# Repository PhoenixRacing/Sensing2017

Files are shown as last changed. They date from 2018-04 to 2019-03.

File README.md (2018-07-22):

# Olin College of Engineering Baja Electrical Subteam Repository

## Backbox

Contains the back-end files (.ino) for the various Arduinos responsible for communication and various tasks relating to reading in sensor data and passing it to the dashboard and SD card.

## Dashboard

Contains the files (.ino) necessary for communicating between the dashboard Arduino and the backbox, as well as for displaying information to the driver as well as logging the information the SD card.

## Dependencies

Contains the libraries necessary to making the code compile on the Arduinos.

## Examples

Contains example code for the various components of the electrical subsystem (refer to system architecture diagram); utilize this for reference for skeleton code.

## LogFiles

Contains (or will contain) the log files saved on the SD card from the car. Will either be in .csv or.xlsx format.

## Outdated Code

Contains archival code from past years that has been ommitted for various reasons (didn't work, redone, unnecessary).

## i2cSlaveTest

Will be absorbed underneath Examples directory eventually. Contains example code for a test for communication between two Arduinos over i2c.

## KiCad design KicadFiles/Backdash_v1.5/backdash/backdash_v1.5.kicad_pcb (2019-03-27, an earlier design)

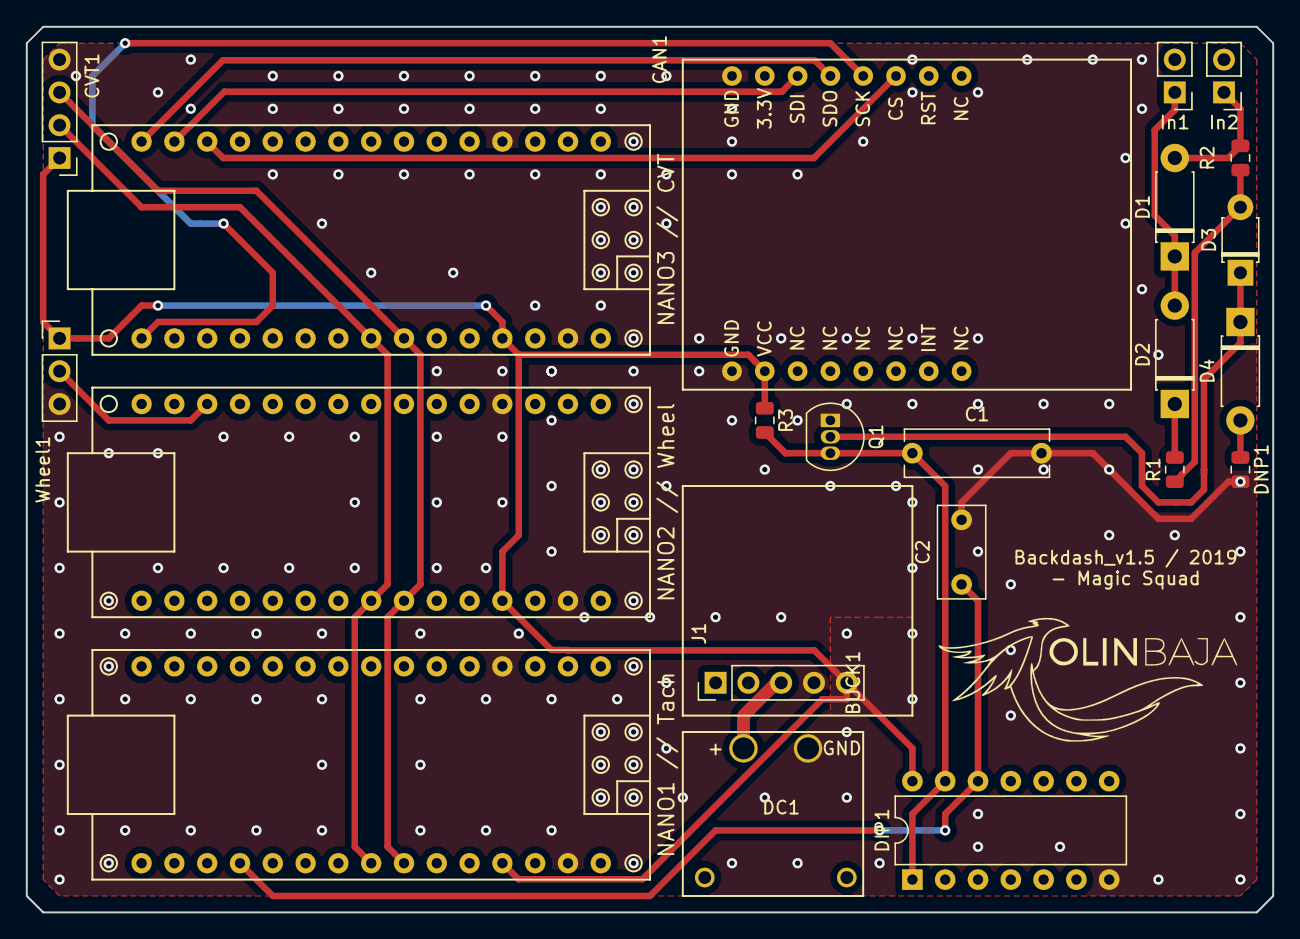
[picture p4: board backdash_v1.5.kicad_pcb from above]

Board: 2 copper layers, 96.5 x 68.6 mm, 22 parts (0 on the bottom side), 19 nets.

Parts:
BUCK1: Conn_01x05_Female; Buck_module
C1: 2200pF; C_Rect_L11.0mm_W3.5mm_P10.00mm_MKT
C2: 39nF; C_Rect_L7.0mm_W3.5mm_P5.00mm
CAN1: Conn_01x16_Female; CAN_Module
CVT1: Conn_01x04_Female; PinHeader_1x04_P2.54mm_Vertical
D1, D2: 1N4007; D_DO-41_SOD81_P7.62mm_Horizontal
D3: 1N4148; D_T-1_P5.08mm_Horizontal
D4: 1N4738; D_DO-41_SOD81_P7.62mm_Horizontal
DC1: Conn_01x04_Female; DC_Connector
DIP1: SN74HC14N; DIP-14_W7.62mm
DNP1: DNP; R_0805_2012Metric
In1: Vin +; PinHeader_1x02_P2.54mm_Vertical
In2: Vin-; PinHeader_1x02_P2.54mm_Vertical
NANO1 // Tach, NANO2 // Wheel, NANO3 // CVT: Conn_01x30_Female; arduino_nano
Q1: 2N3904; TO-92_Inline
R1, R2: 10k; R_0805_2012Metric
R3: 4.7k; R_0805_2012Metric
Wheel1: Conn_01x03_Female; PinHeader_1x03_P2.54mm_Vertical

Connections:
/+: BUCK1.3, DC1.2
/A0: C2.1, DIP1.12, NANO1 // Tach.19
/A4: CVT1.2, NANO1 // Tach.23, NANO2 // Wheel.23, NANO3 // CVT.23
/A5: CVT1.3, NANO1 // Tach.24, NANO2 // Wheel.24, NANO3 // CVT.24
/CS: CAN1.6, NANO3 // CVT.13
/D10: NANO2 // Wheel.13, Wheel1.2
/GND: BUCK1.4, C1.2, C2.2, CAN1.1, CAN1.16, CVT1.4, DC1.1, DIP1.7, DNP1.2, NANO1 // Tach.4, NANO1 // Tach.29, NANO2 // Wheel.4, NANO2 // Wheel.29, NANO3 // CVT.4, NANO3 // CVT.29, Q1.1, Wheel1.3
/RST: CAN1.7, NANO1 // Tach.3, NANO1 // Tach.28, NANO2 // Wheel.3, NANO2 // Wheel.28, NANO3 // CVT.3, NANO3 // CVT.28
/SCK: CAN1.5, NANO3 // CVT.16
/SDI: CAN1.3, NANO3 // CVT.14
/SDO: CAN1.4, NANO3 // CVT.15
/VCC: BUCK1.5, CAN1.15, CVT1.1, DIP1.14, NANO1 // Tach.27, NANO2 // Wheel.27, NANO3 // CVT.27, R3.1, Wheel1.1
unnamed: C1.1, DIP1.1, DIP1.13, Q1.3, R3.2
unnamed: D1.1, D2.2, In1.1
unnamed: D1.2, In2.1, R2.1
unnamed: D2.1, R1.2
unnamed: D3.1, D4.1, Q1.2
unnamed: D3.2, R1.1, R2.2
unnamed: D4.2, DNP1.1

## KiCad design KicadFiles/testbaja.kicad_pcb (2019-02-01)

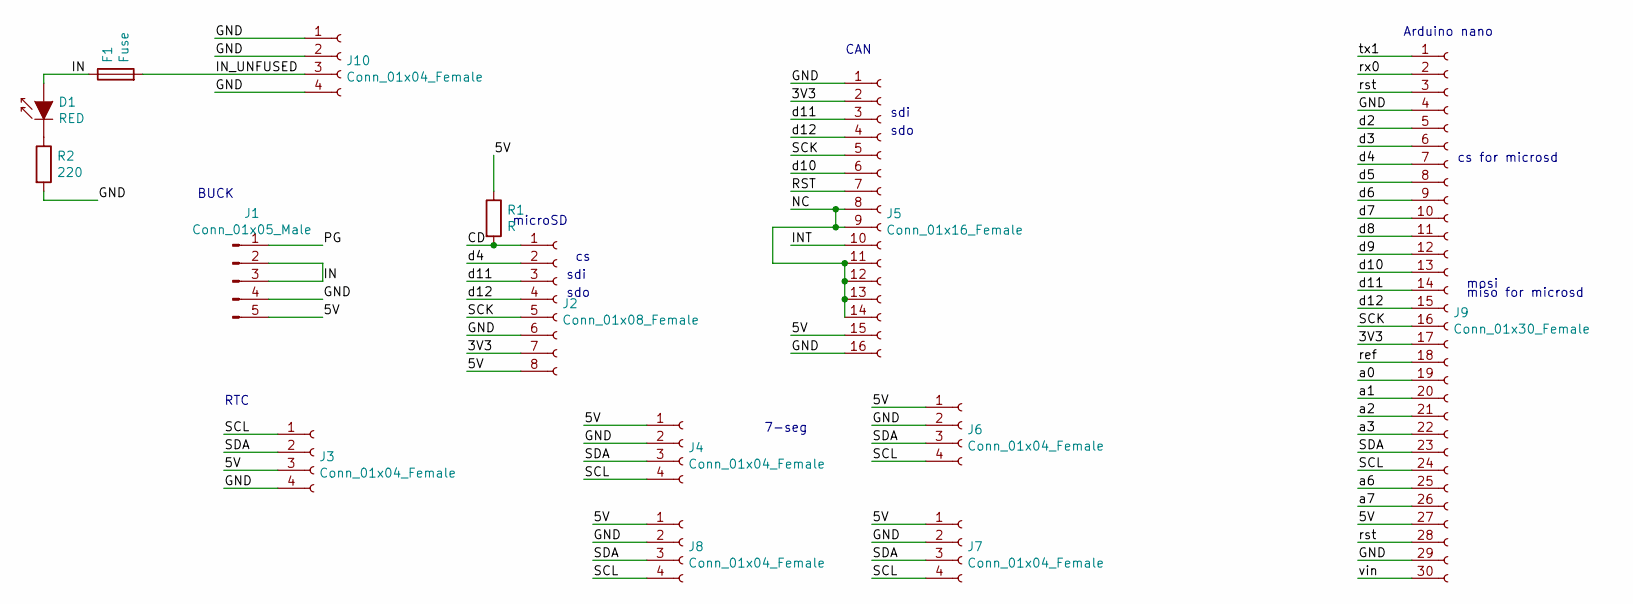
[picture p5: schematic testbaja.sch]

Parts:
D1: RED; LED_D5.0mm_FlatTop
F1: Fuse; Fuse_0ZCFSeries
J1: Conn_01x05_Male; Buck_module
J2: Conn_01x08_Female; microSD_module
J3: Conn_01x04_Female; RealTimeClock
J4, J6, J7, J8: Conn_01x04_Female; 7_segment_display
J5: Conn_01x16_Female; CAN_Module
J9: Conn_01x30_Female; arduino_nano
J10: Conn_01x04_Female; DC_Connector
R1: R; R_1206_3216Metric_Pad1.42x1.75mm_HandSolder
R2: 220; R_0805_2012Metric

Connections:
/3V3: J2.7, J5.2, J9.17
/5V: J1.5, J2.8, J3.3, J4.1, J5.15, J6.1, J7.1, J8.1, J9.27, R1.1
/CD: J2.1, R1.2
/GND: J1.4, J2.6, J3.4, J4.2, J5.1, J5.16, J6.2, J7.2, J8.2, J9.4, J9.29, J10.1, J10.2, J10.4, R2.2
/IN: D1.2 (A), F1.1, J1.2, J1.3
/INT: J5.10
/IN_UNFUSED: F1.2, J10.3
/NC: J5.8, J5.9, J5.11, J5.12, J5.13, J5.14
/PG: J1.1
/RST: J5.7
/SCK: J2.5, J5.5, J9.16
/SCL: J3.1, J4.4, J6.4, J7.4, J8.4, J9.24
/SDA: J3.2, J4.3, J6.3, J7.3, J8.3, J9.23
/a0: J9.19
/a1: J9.20
/a2: J9.21
/a3: J9.22
/a6: J9.25
/a7: J9.26
/d2: J9.5
/d3: J9.6
/d4: J2.2, J9.7
/d5: J9.8
/d6: J9.9
/d7: J9.10
/d8: J9.11
/d9: J9.12
/d10: J5.6, J9.13
/d11: J2.3, J5.3, J9.14
/d12: J2.4, J5.4, J9.15
/ref: J9.18
/rst: J9.3, J9.28
/rx0: J9.2
/tx1: J9.1
/vin: J9.30
unnamed: D1.1 (K), R2.1

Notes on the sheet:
microSD
BUCK
RTC
7-seg
CAN
Arduino nano
cs for microsd
miso for microsd
mosi
sdi
sdo

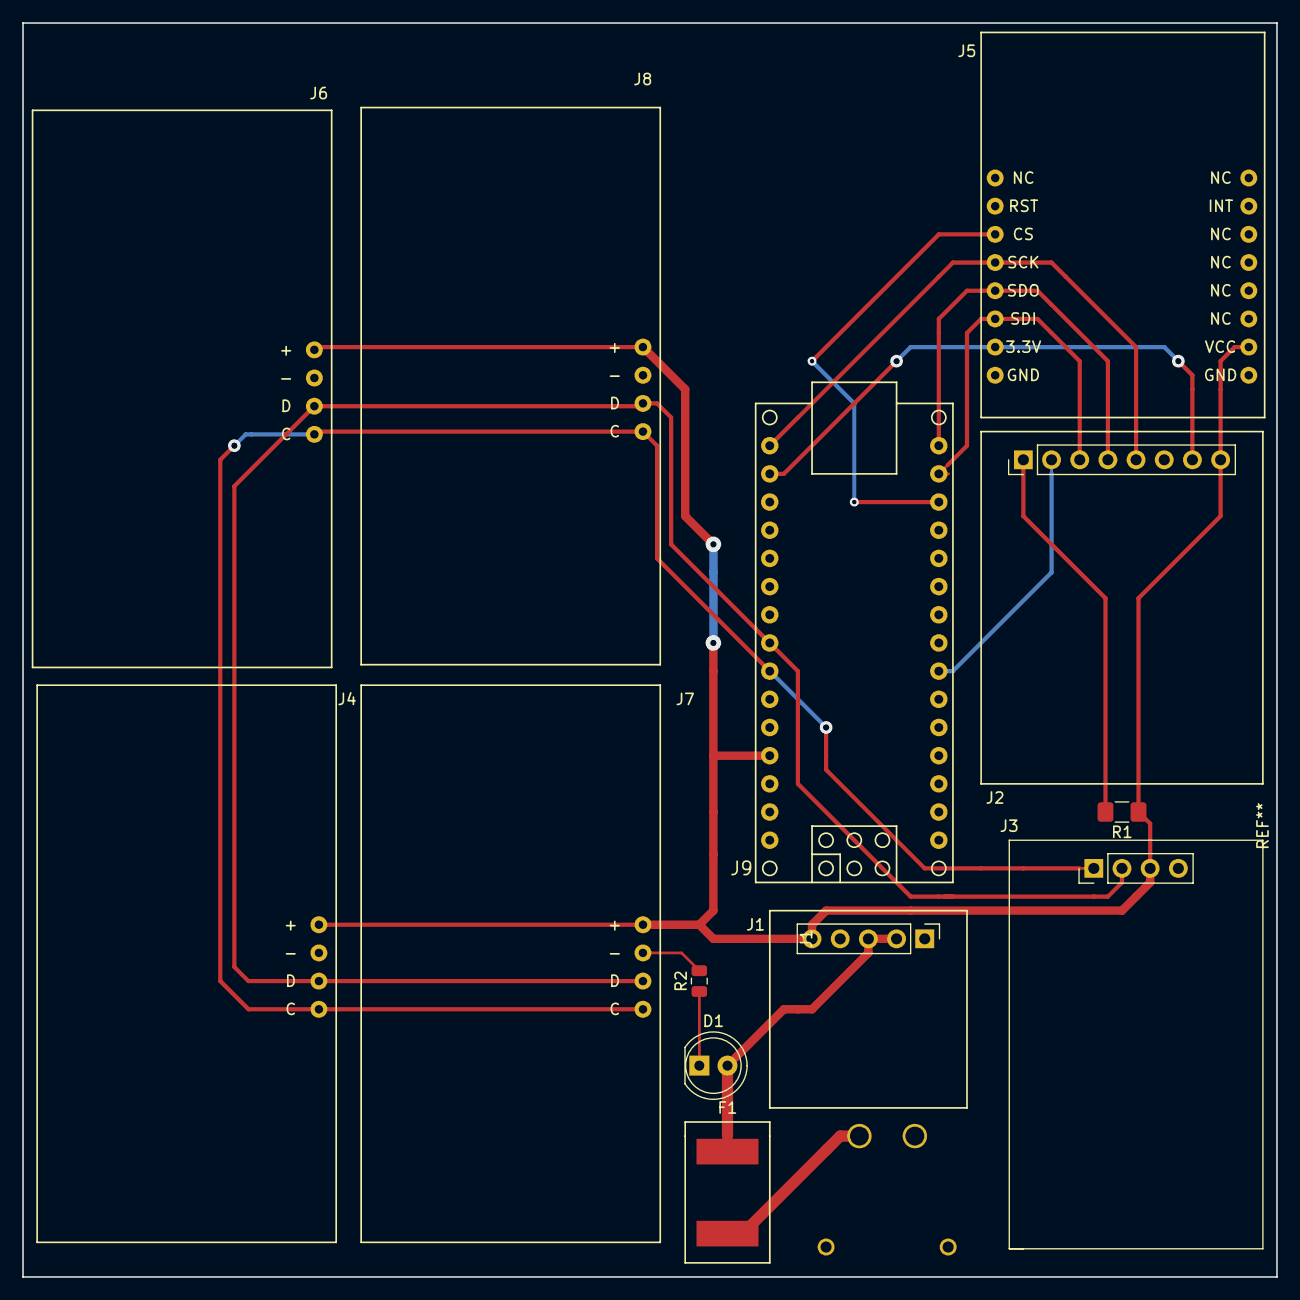
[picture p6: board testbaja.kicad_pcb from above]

Board: 2 copper layers, 113.0 x 113.0 mm, 14 parts (1 on the bottom side), 16 nets.

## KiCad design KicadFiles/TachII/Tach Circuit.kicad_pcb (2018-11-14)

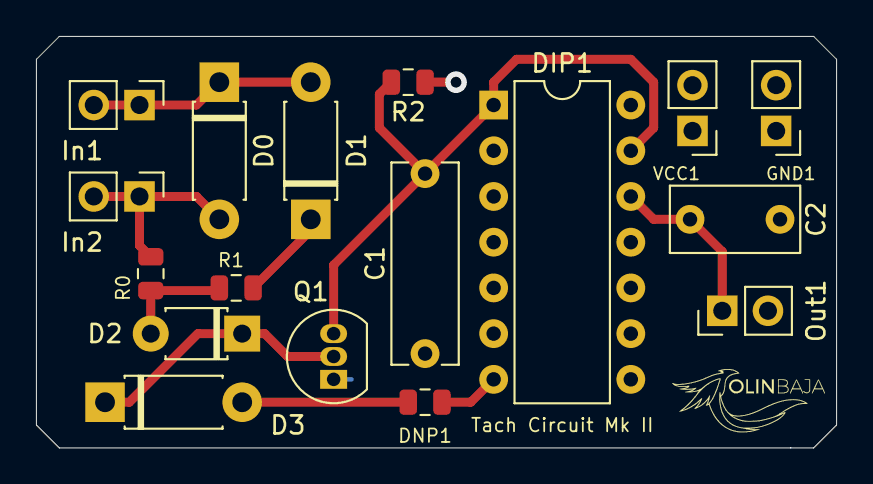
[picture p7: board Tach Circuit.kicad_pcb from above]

Board: 2 copper layers, 44.4 x 22.9 mm, 17 parts (0 on the bottom side), 10 nets.

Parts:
C1: 2200pF; C_Rect_L11.0mm_W3.5mm_P10.00mm_MKT
C2: 39nF; C_Rect_L7.0mm_W3.5mm_P5.00mm
D0, D1: 1N4007; D_DO-41_SOD81_P7.62mm_Horizontal
D2: 1N4148; D_T-1_P5.08mm_Horizontal
D3: 1N4738; D_DO-41_SOD81_P7.62mm_Horizontal
DIP1: SN74HC14N; DIP-14_W7.62mm
DNP1: DNP; R_0805_2012Metric
GND1: GND; PinHeader_1x02_P2.54mm_Vertical
In1: Vin +; PinHeader_1x02_P2.54mm_Vertical
In2: Vin-; PinHeader_1x02_P2.54mm_Vertical
Out1: Vout; PinHeader_1x02_P2.54mm_Vertical
Q1: 2N3904; TO-92_Inline
R0, R1: 10k; R_0805_2012Metric
R2: 4.7k; R_0805_2012Metric
VCC1: 5V; PinHeader_1x02_P2.54mm_Vertical

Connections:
+5V: DIP1.14, R2.1, VCC1.1
GND: C1.2, C2.2, DIP1.7, DNP1.2, GND1.1, Q1.1
unnamed: C1.1, DIP1.1, DIP1.13, Q1.3, R2.2
unnamed: C2.1, DIP1.12, Out1.1
unnamed: D0.1, D1.2, In1.1
unnamed: D0.2, In2.1, R0.1
unnamed: D1.1, R1.2
unnamed: D2.1, D3.1, Q1.2
unnamed: D2.2, R0.2, R1.1
unnamed: D3.2, DNP1.1

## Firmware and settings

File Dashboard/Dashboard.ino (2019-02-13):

/*
 *  - Check for data from CAN --> for the time being just if(True) {
 *  --> update averages --> acceptSample(&tach, analogRead(1)) (inside if statement)
 *  - write to displays
 *  - check if it's been long enough since SD write
 *  --> write to SD --> read RTC
 *  - clear averages
 *  
 *               AT REAR | AT DASH | DISPLAY
 * Wheel Speed | *100    | /100    | 0-40mph
 * Tach        | *1      | *1      | 1000-4000
 * GB Temp     | *1      | *1      | 10-120 C
 * CVT Temp    | *1      | *1      | 10-120 C
 */

//#define DEBUG

/*ERROR CODES:
E 01: RTC failed initialization
E 02: RTC time has been lost
E 03: SD failed initialization
E 04: CAN failed initialization
E 05: File creation failed
*/

#include <Wire.h>
#include <Adafruit_GFX.h>
#include "Adafruit_LEDBackpack.h"
#include "RTClib.h"
#include <SPI.h>
#include <SD.h>
#include <mcp_can.h>
/* Display segment layout:

     8
   -----
 3| 2  |7
   -----
 4| 5  |6
   -----  .1

*/

#define LETTER_O B00111111
#define LETTER_L B00111000
#define LETTER_I B00000110
#define LETTER_n B01010100
#define LETTER_b B01111100
#define LETTER_A B01110111
#define LETTER_J B00011110
#define LETTER_E B01111001
#define LETTER_r B01010000

RTC_DS3231 rtc;
File logFile;
char fileName[13];
boolean logFlag = false;


#define SPEEDO_POS 0
#define TACH_POS 1
#define CVT_POS 2
#define GEARBOX_POS 3

#define BUTTON_PIN 2 //logger button pin 2

#define REFRESH_TIME 100

#define ERROR_DISPLAY_TIME 500

//long unsigned int rxId = 0x101;
#define DATA_LEN 4
uint8_t rxBuf[DATA_LEN*sizeof(int)];         //raw data from CAN
unsigned int recentData[DATA_LEN];             //data from CAN converted back to ints
//#define CAN0_INT 2                          // Set INT to pin 2
MCP_CAN CAN0(10);                           // Set CS to pin 10


typedef struct {
  float sum;
  int count;
} average_data;

average_data tach;
average_data speedo;
average_data cvtTemp;
average_data gearBoxTemp;

void acceptSample(average_data *avg, float data) {
  avg -> sum += data;
  avg -> count++;
}

float getAverage(average_data *avg) {
    float sum = avg -> sum;
    int n = avg -> count;
    return (sum/n);
}

void resetAverage(average_data *avg) {
  avg -> sum = 0;
  avg -> count = 0;
}

Adafruit_7segment tachDisp = Adafruit_7segment();
Adafruit_7segment speedoDisp = Adafruit_7segment();
Adafruit_7segment cvtTempDisp = Adafruit_7segment();
Adafruit_7segment gearBoxTempDisp = Adafruit_7segment();

void initializeDisplays(){
  tachDisp.begin(0x73);
  speedoDisp.begin(0x70);
  cvtTempDisp.begin(0x74);
  gearBoxTempDisp.begin(0x72);
  tachDisp.setBrightness(15);
  speedoDisp.setBrightness(15);
  cvtTempDisp.setBrightness(15);
  gearBoxTempDisp.setBrightness(15);
}

void writeDisplays(){
  tachDisp.writeDisplay();
  speedoDisp.writeDisplay();
  cvtTempDisp.writeDisplay();
  gearBoxTempDisp.writeDisplay();
}

void displayStartup(){
  speedoDisp.writeDigitRaw(0,LETTER_O);
  speedoDisp.writeDigitRaw(1,LETTER_L);
  speedoDisp.writeDigitRaw(3,LETTER_I);
  speedoDisp.writeDigitRaw(4,LETTER_n);
  tachDisp.writeDigitRaw(0,LETTER_b);
  tachDisp.writeDigitRaw(1,LETTER_A);
  tachDisp.writeDigitRaw(3,LETTER_J);
  tachDisp.writeDigitRaw(4,LETTER_A);
  cvtTempDisp.println(2017);
  gearBoxTempDisp.println(2018);
  writeDisplays();
}

void displayZero(){
  tachDisp.println(0);
  speedoDisp.println(0);
  cvtTempDisp.println(0);
  gearBoxTempDisp.println(0);
  writeDisplays();
}

void displayClear(){
  tachDisp.println();
  speedoDisp.println();
  cvtTempDisp.println();
  gearBoxTempDisp.println();
  writeDisplays();
}

void displayError(int code){
  gearBoxTempDisp.writeDigitRaw(0,LETTER_E);
  gearBoxTempDisp.writeDigitRaw(1,LETTER_r);
  gearBoxTempDisp.writeDigitNum(3,int(code/10));
  gearBoxTempDisp.writeDigitNum(4,code%10);
  gearBoxTempDisp.drawColon(1);
  writeDisplays();
}

#define WRITE_INTERVAL 5000

unsigned long lastWriteTime = 0;

void writeLine(unsigned int tachData, float speedData, unsigned int cvtData, unsigned int gbData, boolean logger){
  DateTime logTime = rtc.now();
  char line[27];
  char MM[4];
  char SS[4];
  char SPED[6];
  char TACH[6];
  char CVT[5];
  char GBT[5];
  char F[3];

  if(logger) {
    F[0] = '1';
  }
  else {
    F[0] = '0';
  }
  F[1] = ',';
    
  sprintf(line,"%02d:", logTime.hour());
  sprintf(MM, "%02d:", logTime.minute());
  sprintf(SS, "%02d,", logTime.second());
  //sprintf included with arduino does not handle floats, so this:
  sprintf(SPED, "%02d.%01d,", int(speedData), (round(speedData*10)%10));
  sprintf(TACH, "%04d,", tachData);
  sprintf(CVT, "%03d,", round(cvtData));
  sprintf(GBT, "%03d,", round(gbData));

  strcat(line, MM);
  strcat(line, SS);
  strcat(line, SPED);
  strcat(line, TACH);
  strcat(line, CVT);
  strcat(line, GBT);
  strcat(line, F);

  #ifdef DEBUG
    Serial.println(line);
  #endif

  logFile = SD.open(fileName, FILE_WRITE);
  if(logFile){
    logFile.println(line);
    logFile.close();
  }
}

void setup() {
#ifdef DEBUG
  Serial.begin(9600);
  Serial.println("Starting Dash Display and Logger in Debug Mode...");
#endif

  initializeDisplays();

  Wire.begin();        // Activate I2C link

  displayStartup();
  delay(3000);
  displayZero();
  pinMode(BUTTON_PIN,INPUT_PULLUP);

  if(!rtc.begin()){
    displayError(1);
    #ifdef DEBUG
      Serial.println("RTC failed initialization");
    #endif
    delay(ERROR_DISPLAY_TIME);
  }

  if (rtc.lostPower()) {
    displayError(2);
    #ifdef DEBUG
      Serial.println("RTC time has been lost");
    #endif
    delay(ERROR_DISPLAY_TIME);
  }

  if (!SD.begin(4)){
    displayError(3);
    #ifdef DEBUG
      Serial.println("SD failed initialization");
    #endif
    delay(ERROR_DISPLAY_TIME);
  }


  // Initialize MCP2515 running at 16MHz with a baudrate of 500kb/s and the masks and filters disabled.
  if(!CAN0.begin(MCP_ANY, CAN_500KBPS, MCP_16MHZ) == CAN_OK){
    displayError(4);
    #ifdef DEBUG
      Serial.println("CAN failed initialization");
    #endif
    delay(ERROR_DISPLAY_TIME);
  }


  
  CAN0.setMode(MCP_NORMAL);                     // Set operation mode to normal so the MCP2515 sends acks to received data. //makes the Message Sent successfully on the RX side. 
  //pinMode(CAN0_INT, INPUT);                     // Configuring pin for /INT input

  DateTime now = rtc.now();
  char MO[3];
  char DD[3];
  char HH[3];
  char MI[3];
  sprintf(MO, "%02d", now.month());
  sprintf(DD, "%02d", now.day());
  sprintf(HH, "%02d", now.hour());
  sprintf(MI, "%02d", now.minute());
  strcat(fileName, MO);
  strcat(fileName, DD);
  strcat(fileName, HH);
  strcat(fileName, MI);
  strcat(fileName,".CSV");
  #ifdef DEBUG
    Serial.println(fileName);
  #endif

  logFile = SD.open(fileName, FILE_WRITE);


  if(!logFile){
    displayError(5);
    #ifdef DEBUG
      Serial.println("File creation failed");
    #endif
    delay(5000);


  }
  logFile.close();
}

void loop() {
  
  if (!digitalRead(BUTTON_PIN)) {
    logFlag = true;
  }

  CAN0.readMsgBuf(0x101, DATA_LEN, rxBuf);
  memcpy(recentData,rxBuf,DATA_LEN*sizeof(int));

  acceptSample(&tach, recentData[0]);
  acceptSample(&speedo, recentData[1]);
  acceptSample(&cvtTemp, recentData[2]);
  acceptSample(&gearBoxTemp, recentData[3]);
  //Serial.println(realData[0]);

  speedoDisp.printFloat((float)recentData[SPEEDO_POS]/100,1);
  tachDisp.println(recentData[TACH_POS]);
  cvtTempDisp.println(recentData[CVT_POS]);
  gearBoxTempDisp.println(recentData[GEARBOX_POS]);

  writeDisplays();

  if (millis() - lastWriteTime > WRITE_INTERVAL) {
    unsigned int logTach = (getAverage(&tach));
    float logSpeedo = (getAverage(&speedo))/100;
    unsigned int logCvt = (getAverage(&cvtTemp));
    unsigned int logGb = (getAverage(&gearBoxTemp));
    writeLine(logTach, logSpeedo, logCvt, logGb, logFlag);
    logFlag = false;
  #ifdef DEBUG
    Serial.println("Writing line to SD card");
  #endif
    lastWriteTime = millis();
    resetAverage(&tach);
    resetAverage(&speedo);
    resetAverage(&cvtTemp);
    resetAverage(&gearBoxTemp);
  }
}

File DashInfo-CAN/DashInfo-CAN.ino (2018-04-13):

#define DEBUG

/*ERROR CODES:
E 01: RTC failed initialization
E 02: RTC time has been lost
E 03: SD failed initialization
E 04: File creation failed
*/

#include <Wire.h>
#include <Adafruit_GFX.h>
#include "Adafruit_LEDBackpack.h"
#include "RTClib.h"
#include <SPI.h>
#include <SD.h>
/* Display segment layout:

     8
   -----
 3| 2  |7
  -----
4| 5  |6
 -----  .1

*/

uint8_t O = B00111111;
uint8_t L = B00111000;
uint8_t I = B00000110;
uint8_t n = B01010100;
uint8_t b = B01111100;
uint8_t A = B01110111;
uint8_t J = B00011110;
uint8_t E = B01111001;
uint8_t r = B01010000;

RTC_DS3231 rtc;
File logFile;
char fileName[13];
boolean logFlag = false;

#define BUTTON_PIN 2 //logger button pin 2

#define PAYLOAD_SIZE 2 // how many bytes to expect from each I2C salve node
#define NODE_MAX 4 // maximum number of slave nodes (I2C addresses) to probe
#define START_NODE 2 // The starting I2C address of slave nodes
//#define NODE_READ_DELAY 1 // Some delay between I2C node reads

const int refreshTime = 100;

typedef struct {
  float sum;
  int count;
} average_data;

average_data tach;
average_data speedo;
average_data cvtTemp;
average_data gearBoxTemp;

unsigned int recentData[4];


void acceptSample(average_data *avg, float data) {
  avg -> sum += data;
  avg -> count++;
}

float getAverage(average_data *avg) {
    float sum = avg -> sum;
    int n = avg -> count;
    return (sum/n);
}

void resetAverage(average_data *avg) {
  avg -> sum = 0;
  avg -> count = 0;
}

Adafruit_7segment tachDisp = Adafruit_7segment();
Adafruit_7segment speedoDisp = Adafruit_7segment();
Adafruit_7segment cvtTempDisp = Adafruit_7segment();
Adafruit_7segment gearBoxTempDisp = Adafruit_7segment();

void initializeDisplays(){
  tachDisp.begin(0x70);
  speedoDisp.begin(0x73);
  cvtTempDisp.begin(0x74);
  gearBoxTempDisp.begin(0x72);
  tachDisp.setBrightness(15);
  speedoDisp.setBrightness(15);
  cvtTempDisp.setBrightness(15);
  gearBoxTempDisp.setBrightness(15);
}

void writeDisplays(){
  tachDisp.writeDisplay();
  speedoDisp.writeDisplay();
  cvtTempDisp.writeDisplay();
  gearBoxTempDisp.writeDisplay();
}

void displayStartup(){
  tachDisp.writeDigitRaw(0,O);
  tachDisp.writeDigitRaw(1,L);
  tachDisp.writeDigitRaw(3,I);
  tachDisp.writeDigitRaw(4,n);
  speedoDisp.writeDigitRaw(0,b);
  speedoDisp.writeDigitRaw(1,A);
  speedoDisp.writeDigitRaw(3,J);
  speedoDisp.writeDigitRaw(4,A);
  cvtTempDisp.println(2017);
  gearBoxTempDisp.println(2018);
  writeDisplays();
}

void displayZero(){
  tachDisp.println(0);
  speedoDisp.println(0);
  cvtTempDisp.println(0);
  gearBoxTempDisp.println(0);
  writeDisplays();
}

void displayClear(){
  tachDisp.println();
  speedoDisp.println();
  cvtTempDisp.println();
  gearBoxTempDisp.println();
  writeDisplays();
}

void displayError(int code){
  gearBoxTempDisp.writeDigitRaw(0,E);
  gearBoxTempDisp.writeDigitRaw(1,r);
  gearBoxTempDisp.writeDigitNum(3,int(code/10));
  gearBoxTempDisp.writeDigitNum(4,code%10);
  gearBoxTempDisp.drawColon(1);
  writeDisplays();
}

//unsigned int recentTach;
//float recentSpeedo;
//float recentCvtTemp;
//float recentGearBoxTemp;

const int maxTime = 5000;

unsigned long lastWriteTime = 0;

unsigned int receiveData(){
  byte payload[PAYLOAD_SIZE];
  for(byte i = 0; i < PAYLOAD_SIZE; i ++){
    payload[i] = Wire.read();
  }
  unsigned int data = *((unsigned int*)payload);
  return data;
}

const int wheelDia = 22;
const int spokes = 6;

unsigned int convertToRPM(unsigned int freq){
  //RPM:
  unsigned int RPM = freq*2;
  return RPM;
}



void writeLine(unsigned int tachData, float speedData, float cvtData, float gbData, boolean logger){
  DateTime logTime = rtc.now();
  char line[33];
  char MM[4];
  char SS[4];
  char TACH[6];
  char SPED[6];
  char CVTTE[7];
  char GBTEM[7];
  char F[2];


  if(logger) {
    F[0] = "1";
  }
  else {
    F[0] ="0";
  }
  
  
  sprintf(line, "%02d:", logTime.hour());
  sprintf(MM, "%02d:", logTime.minute());
  sprintf(SS, "%02d,", logTime.second());
  sprintf(TACH, "%04d,", getAverage(recentData[0]));
  //sprintf included with arduino does not handle floats, so this:
  sprintf(SPED, "%02d.%01d,", int(getAverage(recentData[1])), (round(getAverage(recentData[1])*10)%10));
  sprintf(CVTTE, "%03d.%01d,", int(getAverage(recentData[2])), (round(getAverage(recentData[2])*10)%10));
  sprintf(GBTEM, "%03d.%01d,", int(getAverage(recentData[3])), (round(getAverage(recentData[3])*10)%10));

  strcat(line, MM);
  strcat(line, SS);
  strcat(line, TACH);
  strcat(line, SPED);
  strcat(line, CVTTE);
  strcat(line, GBTEM);
  strcat(line, F);

  Serial.println(line);

  logFile = SD.open(fileName, FILE_WRITE);
  if(logFile){
    logFile.println(line);
    logFile.close();
  }
}

float convertToSpeed(unsigned int freq){
  //MPH:
  float circ = wheelDia * 3.1416;
  //(freq pulses/1 min)(1 rev/spokes pulses)(circ in/1 rev)(1 ft/12 in)(1 mi/5280 ft)(60 min/1 hr)
  float converter = (circ*60)/(spokes*12*5280);
  float speedMPH = round(freq * converter * 100)/100;
  return speedMPH;
}

float convertToTemp(unsigned int temp100){
  return temp100/100;
}


void setup() {
#ifdef DEBUG
  Serial.begin(9600);
  Serial.println("Starting Dash Display and Logger...");
#endif

  initializeDisplays();

  Wire.begin();        // Activate I2C link

  displayStartup();
  delay(3000);
  displayZero();
  pinMode(BUTTON_PIN,INPUT_PULLUP);

  if(!rtc.begin()){
    displayError(1);
    #ifdef DEBUG
      Serial.println("RTC failed initialization");
    #endif
    delay(5000);
  }

  if (rtc.lostPower()) {
    displayError(2);
    #ifdef DEBUG
      Serial.println("RTC time has been lost");
    #endif
    delay(5000);
  }

  if (!SD.begin(4)){
    displayError(3);
    #ifdef DEBUG
      Serial.println("SD failed initialization");
    #endif
    delay(5000);
  }

  DateTime now = rtc.now();
  char MO[3];
  char DD[3];
  char HH[3];
  char MI[3];
  sprintf(MO, "%02d", now.month());
  sprintf(DD, "%02d", now.day());
  sprintf(HH, "%02d", now.hour());
  sprintf(MI, "%02d", now.minute());
  strcat(fileName, MO);
  strcat(fileName, DD);
  strcat(fileName, HH);
  strcat(fileName, MI);
  strcat(fileName,".CSV");
  #ifdef DEBUG
    Serial.println(fileName);
  #endif

  logFile = SD.open(fileName, FILE_WRITE);
  if(!logFile){
    displayError(4);
    #ifdef DEBUG
      Serial.println("File creation failed");
    #endif
    delay(5000);
  }
  logFile.close();
}



void loop() {
  
//  recentTach = analogRead(0);
//  recentSpeedo = analogRead(1)/100;
//  recentCvtTemp = analogRead(2)/10;
//  recentGearBoxTemp = analogRead(3)/10;
    

  if (!digitalRead(BUTTON_PIN)) {
    logFlag = true;
  }
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

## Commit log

2017-10-20 Add rolling average example code and i2c example code
2017-10-25 Add hall effect sensor
2017-10-27 i2c frequency sampling, averaging, and sending working!
2017-11-01 Adds integration between i2c and 77
2017-11-02 Added example log files
    [LogExample.csv, LogExample.xlsx]
2017-11-15 Add CVT heat sensing
2017-12-06 commented out log button
2017-12-08 Fixed a few things
    [SensingCollector.ino]
2018-02-09 data logger not working
    [DashInfo-CAN.ino]
2018-02-20 CAN click TX and RX, not working fully.
    [can-spi-rx-mcplib.ino, can-spi-tx-mcplib.ino]
2018-03-09 rtd sensor code to integrate later
2018-03-09 "dash info displaying properly, SD card still having write problems"
    [DashInfoCANupdated.ino]
2018-04-11 fixed dash delay problem, reimplemented logger, cleaned up
    [DashInfo-CAN.ino, DashInfoWithCAN.ino, FreqGenTester.ino.ino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]
2018-04-17 commented out i2c sections to see how the can section is doing
2018-04-18 worked on i2c to can
2018-04-20 Started to parse i2c data
2018-04-23 Almost go the whole chain going
2018-04-24 fix spi-can bridge arduino and spi slave
    [DashInfoWithCAN.ino, spiMasterRx.ino]
2018-05-01 I2c sending rtd values
2018-05-01 I2c of rtd works, plus some functionality in freq tester
2018-05-04 missed a file from last commit
    [rtdcopied.ino]
2018-05-08 IR sensor sending thru can to dashboard
2018-05-08 sending multiple messages from one node working in TEMP. Frequency integration started but not working for mph
    [RTDSpeedoNode.ino, TachNode.ino, spiMasterRx_TEMP.ino]
2018-05-11 got the wrong merge lmao
    [RTDSpeedoNode.ino]
2018-09-26 RTC Footprint
2018-09-26 Footprint for Arduino Nano
2018-09-26 created 7 segment display footprint
2018-09-28 CAN module footprint v1
2018-10-03 half done making a board
    [testbaja.kicad_pcb, testbaja.sch]
2018-10-12 DC connector
2018-10-12 all routed
    [testbaja.kicad_pcb]
2018-10-16 all file update before i install ubuntu
    [testbaja.sch]
2018-10-17 Routing needed
    [Tach Circuit.kicad_pcb, Tach Circuit.sch]
2018-10-18 ground = poured
    [Tach Circuit.kicad_pcb, Tach Circuit.sch]
2018-10-19 hopefully this works
    [Tach Circuit-B.Cu.gbr, Tach Circuit-B.Mask.gbr, Tach Circuit-B.Paste.gbr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]
2018-10-19 ORDERED BOARDS
    [testbaja.kicad_pcb, testbaja.sch]
2018-10-31 New and improved and still in progress
    [Tach Circuit.kicad_pcb, Tach Circuit.sch]
2018-11-02 backdash schematic
    [backdash.kicad_pcb, backdash.sch]
2018-11-02 backdash footprints assigned
    [Tach Circuit.kicad_pcb, backdash.sch]
2018-11-07 update backdash
    [backdash.kicad_pcb, backdash.sch]
2018-11-09 bmp to footprint
2018-11-09 Added logo and fixed connectors
    [Tach Circuit.kicad_pcb, Tach Circuit.sch]
2018-11-09 front dash with specific circuitry
    [FrontDash_circuitry.kicad_pcb, FrontDash_circuitry.sch]
2018-11-14 need to add in power
    [backdash.kicad_pcb, backdash.sch]
2018-11-14 Started the circuitry for the backdash version 2
    [Backdash_v2.kicad_pcb, Backdash_v2.sch]
2018-11-14 logo and batt added
    [backdash.kicad_pcb]
2018-11-14 Starting ATMEGA
    [FrontDash_circuitry.sch]
2018-11-16 nano progress made
    [FrontDash_circuitry.sch]
2018-11-24 Board edge was a little off
    [backdash.kicad_pcb]
2018-11-24 Adding all the gerber files
    [backdash-B.Cu.gbl, backdash-B.Cu.gbr, backdash-B.Mask.gbr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]
2018-11-28 Added can circuitry
    [FrontDash_circuitry.sch]
2018-11-30 nano completed
    [FrontDash_circuitry.sch]
2018-12-05 Front dash mini sd card is almost done
    [FrontDash_circuitry.sch]
2018-12-05 started back dash
    [Backdash_v2.sch, FrontDash_circuitry.sch]
2019-02-01 Fixed frontdash can CS
    [backdash.sch, testbaja.kicad_pcb, testbaja.sch]
2019-02-22 un-deleted schematic
    [backdash.sch]
2019-02-22 added tach sechematic, needs buck footprint
    [backdash.kicad_pcb, backdash.sch]
2019-02-22 pcb is once again messy
    [backdash.sch]
2019-02-27 updating backdash
    [Tach Circuit.sch, TachII.sch, backdash.kicad_pcb]
2019-02-27 Removed RTD, fixed schematic, added tach, looks pretty
    [backdash-B.Cu.gbr, backdash-B.Mask.gbr, backdash-B.Paste.gbr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]
2019-03-06 gerbers exist now
    [backdash_v1.5.kicad_pcb]
2019-03-06 labeled nanos
    [backdash_v1.5.kicad_pcb]
2019-03-06 oops un-deleted logo
    [backdash_v1.5.kicad_pcb]
2019-03-06 yeet gerbers added for real this time
    [backdash_v1.5-B.Cu.gbl, backdash_v1.5-B.Mask.gbs, backdash_v1.5-B.Paste.gbp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]
2019-03-27 fixed gerbers correctly this time I hope
    [backdash_v1.5-B.Cu.gbl, backdash_v1.5-B.Mask.gbs, backdash_v1.5-B.Paste.gbp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]
2019-03-27 hope pcbway likes this one
    [backdash_v1.5-NPTH.drl, backdash_v1.5-PTH.drl]
